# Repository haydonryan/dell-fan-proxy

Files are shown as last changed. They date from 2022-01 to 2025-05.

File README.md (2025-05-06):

# Dell Fan controller
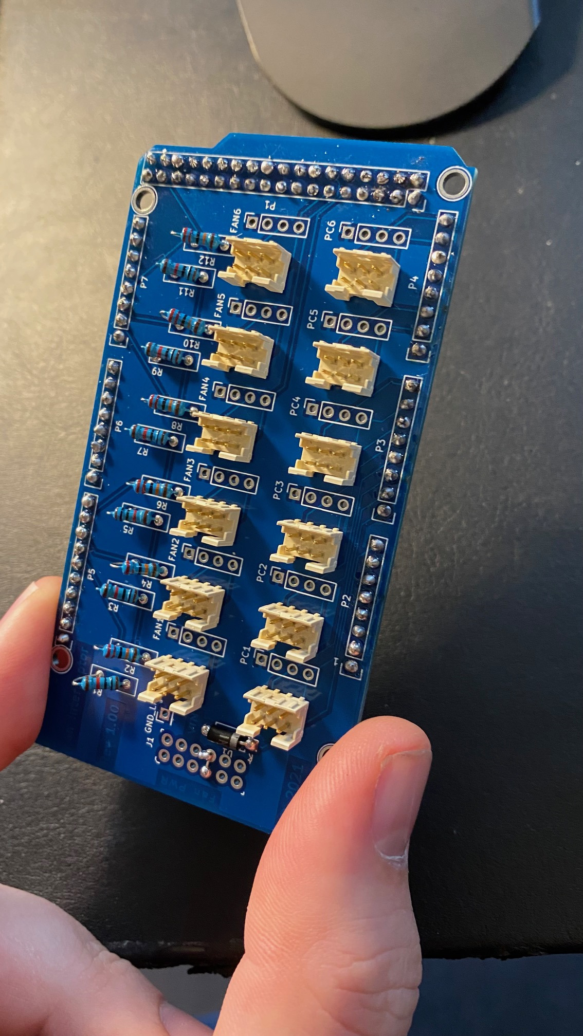
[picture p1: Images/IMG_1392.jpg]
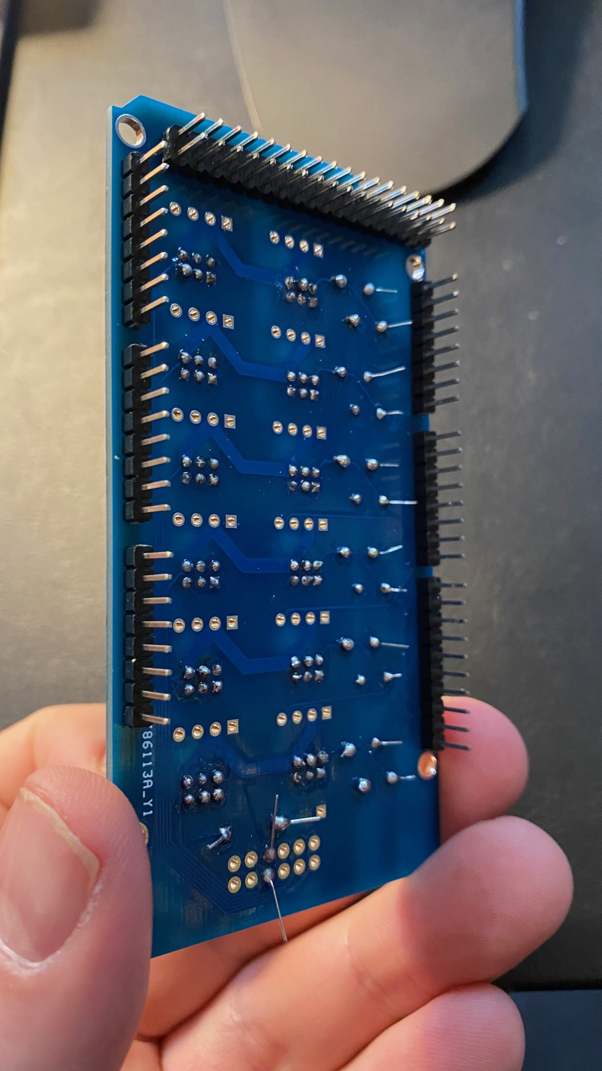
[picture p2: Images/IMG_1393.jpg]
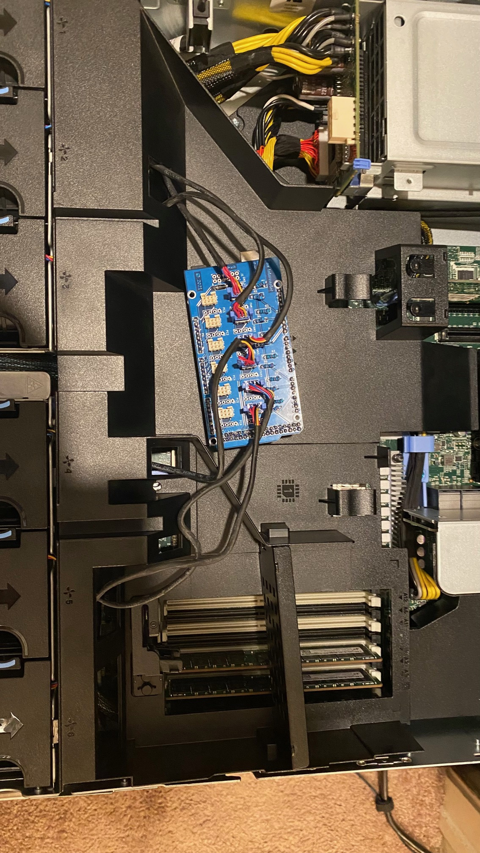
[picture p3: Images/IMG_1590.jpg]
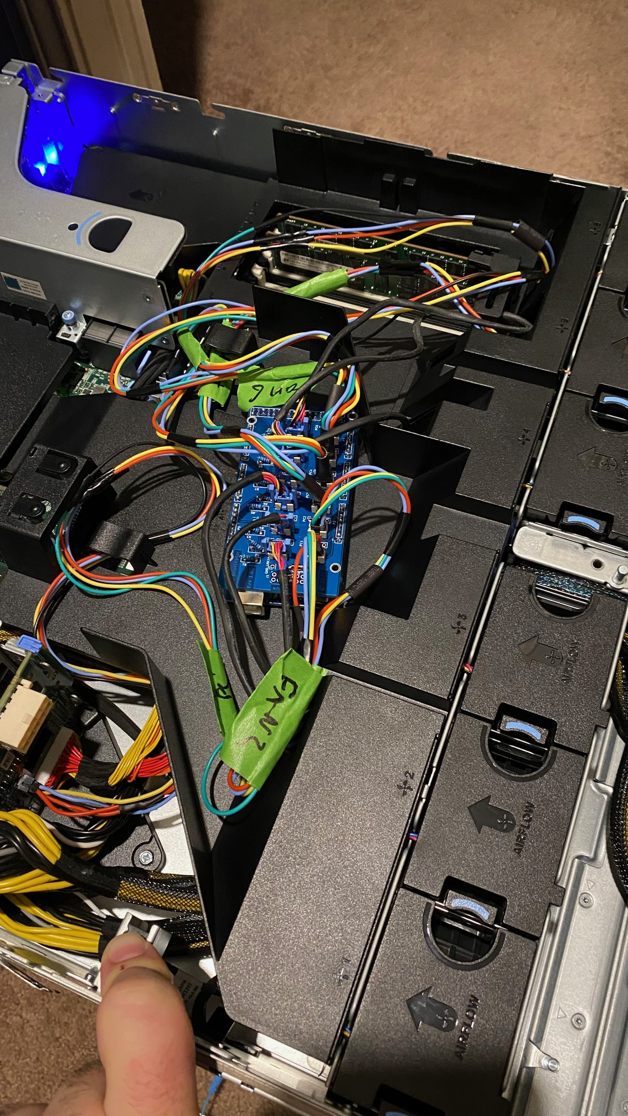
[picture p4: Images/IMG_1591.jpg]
         

Arduino Mega Fan Controller Sheild For R7515, R540 non hot swap fans.

# Background
I run an R7515 in my homelab. It's in a separate room upstairs (from my office) with the door open, I can hear it from my office downstairs.  It makes the room unusable that it sits in.

At 43% FAN, I can barely hear it from downstairs, 35% is really not too bad, up close.

The minimum fan speed and therefore noise is designed for a datacenter next to other heat generating servers with no noise contstraints, not a room in a house.
Plus I've got some non dell hardware( like many others do in homelabs) that the idrac controller doesn't know how to talk to, so the idrac just ramps the fans up to compensate for that one device.

I also noticed that at idle (which the machine sits 90% of the time) there is a 3 degree C differential between inlet and outlet temp, with the cpu being nice and cool.

# Why
- Dell support told me I'm not using the server for it's use case (Datacenter usage) - They're correct.
- Don't want to modify the firmware (it's signed anyways)
- Thought this would be an interesting project tom get more into electronics and control boards.

- As these machines come out of primary service in datacenters people are going to want to lab them - let's give them the power to do that!

# Disclaimer
- Will void your warranty
- Could cause your server to overheat
- Improper connection of fans can short out your motherboard!!!

- No responsibility taken for damaged hardware, loss of income, etc.

# Bill Of Materials:
- 6 Molex 2.00mm 2 Row, 6 Position Rectangular Receptical (Part # 0511100660) ~80c each https://www.digikey.com/en/products/detail/molex/0511100660/1144838?s=N4IgTCBcDaIOoFkCMAOArAdgwWgHIBEQBdAXyA
- 36 Molex Connector Socket 24-30AWG Crimp Gold (Part # 0503948054) 5c each https://www.digikey.com/en/products/detail/molex/0503948054/2404822?s=N4IgTCBcDaIAwFY4GYCcAWAHI9IC6AvkA

- 6 Amphenol ICC Conenctor Through Header Vert 6 Ppos 2.00mm (Part # 98414-G06-06LF) https://www.digikey.com/en/products/detail/amphenol-icc-fci/98414-G06-06LF/1535247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

- 1 Arduino Mega

- 24 AWG hookup wire - 5 colors preferred, but just be careful if you don't have different colors Cheaper on Amazon (https://www.amazon.com/CBAZYTM-Stranded-Flexible-Silicone-Electric/dp/B073RD76QD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)

- 6 TMP36 Temperature Sensors?? ~$1.50 https://www.digikey.com/en/products/detail/analog-devices-inc/TMP36GT9Z/820404

- Shrink wrap for wires
  - https://www.amazon.com/Eventronic-200pcs-Shrink-Tubing-Tubes/dp/B087JHB2CL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
  - https://www.amazon.com/High-Heat-Shrink-Tubing-Tube/dp/B0722HN8SW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
  - https://www.mouser.com/ProductDetail/Qualtek/Q2-F-RK4-1-16-11-6IN-39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

# Random bits of information

By measuring and pulling pins out of the fan, I was able to determine that the pins (with the plastic nib up, facing away from you in the order:
```
1   2   3
4   5   6
```

That the Wires are:

1. Blue - PWM
2. Not connected
3. Black - Ground
4. -| Red - 12v (this wire continues to fan)
5. -| Red - 12v Loopback
6. Yellow - Sense wire.

Arduino Pin	 Register
- 2	OCR3B
- 3	OCR3C
- 4	OCR4C
- 5	OCR3A
- 6	OCR4A
- 7	OCR4B
- 8	OCR4C
- 9	OCR2B
- 10	OCR2A
- 11	OCR1A
- 12	OCR1B
- 13	OCR0A
- 44	OCR5C
- 45	OCR5B
- 46	OCR5A

source: http://astro.neutral.org/arduino/arduino-pwm-pins-frequency.shtml

## Fri Dec 31 11:26:19 2021
Checked the continuity - on the new server board - there's a common 12v rail AND common 12v ground.  This means that I can easily check the fan project using the bench power supply.

So far so good on the server. Printed U shaped spacers to save the cables for fans 1-3.  Definitely prefer to do this over not having anything pushing the top up.

I did find that only fan 3 has 12v power when powered off, the rest must be switched somewhere in the motherboard.

Cable lengths:
- Fan 1 30cm
- Fan 2 26cm
- Fan 3 45cm
- Fan 4 40cm
- Fan 5 35cm
- Fan 6 40cm

Max length shrink tubing at the arduino end: 1-1.5cm

# July 2022 Update
I've been testing this during summer and noticed that as the inlet temperature approaches the limit "for this configuration" the fans ramp significantly.  This is clearly a preventative reaction rather than a reactive one.  Also ensuring that the hardware that is in the server is "compatilbe" aka listed on the compatabilty matrix certainly helps to reduce the speed of the fans.

# May 2024 Update
Have been running my server 24/7 for two years now with no ill effects.  No hardware failures, and just less noise.  It's not perfect and fans seem to surge slightly vs stay flat consistently.  It's not too big of an issue and could probably be adjusted by increasing the time the fans are averaged. Very happy with how this project is running.

# Making cable tips.
Put some shrink tubing on the 12v wire on the loop and the main wire before putting the terminal into the block. Stray 12v is SUPER bad.
Cut the terminal off the tape but leave the small bit of tape on for holding it steady.
put the terminal into the 1.3mm crimp size first all the way up to the tape - it should hold itself in there - making it easier to feed in the cable(s).

Make sure to crimp the actual insulation.
Don't have the wire come out too far as mounting this, the pins will potentially pus the pin out if there's not enough space.
https://www.youtube.com/watch?v=Ta55NTSBLN0

Do the dual power lead crimp first (it's the hardest)

# Possible improvements
It would be much safer to map the fan speed returned to idrac from the detected speed of the fan, not the requested rpm. That way if a fan fails, then idrac will throw a fault.

# Compatability
## Compatible Dell Servers
- R7515 (tested)
- R540 (untested)
- R7415 (untested)

## Incompatible Dell Servers
- R740 / R740XD
- R840
- R7615
- R550
- (anything where the fan plugs directly into the motherboard)

## Unsure
- R240 (unsure if can fit)
- R340 (unsure if can fit)
- R640 (unsure if can fit)

# Resources:
- Starting point: https://www.youtube.com/watch?v=UJK2JF8wOu8
- Replacement Fan: https://www.itcreations.com/product/119156
- Standard 4 pin fan pinout https://allpinouts.org/pinouts/connectors/motherboards/motherboard-cpu-4-pin-fan/
- https://pastebin.com/s49SWw1A
- https://github.com/Max-Sum/HP-fan-proxy/blob/master/hp_fan.ino
- https://www.avdweb.nl/arduino/misc/handy-functions
- https://www.reddit.com/r/homelab/comments/8wbogx/my_attempt_at_creating_a_circuit_board_that/
- https://www.reddit.com/r/homelab/comments/beuks5/silencing_the_hp_dl380_for_good/

- Setting the interrupt priority: https://www.youtube.com/watch?v=H3o08WE0zEI
- Delta Fan Datasheet for similar fan: https://www.mouser.com/datasheet/2/632/dele_s_a0011169984_1-2290125.pdf
- https://homeservershow.com/forums/topic/7294-faking-the-fan-signal/

- https://forum.arduino.cc/t/problem-measuring-4-pin-fan-rpm/666804/6
- http://www.benripley.com/diy/arduino/three-ways-to-read-a-pwm-signal-with-arduino/
- https://www.youtube.com/watch?v=nut1ZiiXzVU&t=143s

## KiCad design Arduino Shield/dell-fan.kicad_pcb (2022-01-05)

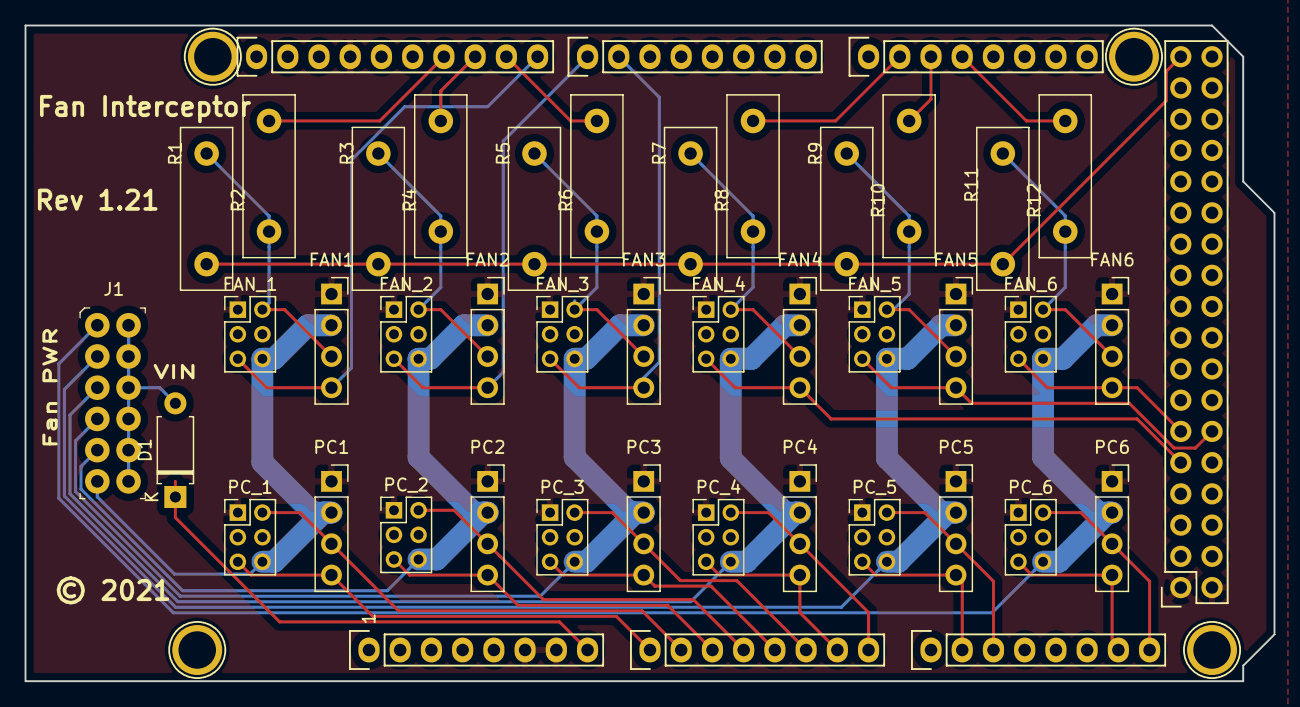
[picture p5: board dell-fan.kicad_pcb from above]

Board: 2 copper layers, 101.6 x 53.3 mm, 49 parts (0 on the bottom side), 40 nets.

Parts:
D1: 1N4007; D_A-405_P7.62mm_Horizontal
FAN1, FAN2, FAN3, FAN4, FAN5, FAN6: To Fan; PinSocket_1x04_P2.54mm_Vertical
FAN_1, FAN_2, FAN_3, FAN_4, FAN_5, FAN_6: To FAN; PinHeader_2x03_P2.00mm_Vertical
J1: Power; PinHeader_6x2_P2.54mm_Horizontal
P1: Digital; Socket_Strip_Arduino_2x18
P2: Power; Socket_Strip_Arduino_1x08
P3, P4: Analog; Socket_Strip_Arduino_1x08
P5: PWM; Socket_Strip_Arduino_1x10
P6: PWM; Socket_Strip_Arduino_1x08
P7: Communication; Socket_Strip_Arduino_1x08
P8, P10, P11, P13: CONN_01X01; Arduino_1pin
PC1, PC2, PC3, PC4, PC5, PC6: To PC; PinSocket_1x04_P2.54mm_Vertical
PC_1, PC_2, PC_3, PC_4, PC_5, PC_6: To PC; PinHeader_2x03_P2.00mm_Vertical
R1, R3, R5, R7, R9, R11: 10k; R_Box_L13.0mm_W4.0mm_P9.00mm
R2, R4, R6, R8, R10, R12: 220k; R_Box_L13.0mm_W4.0mm_P9.00mm

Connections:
+5V: P1.35, P1.36, R1.2, R3.2, R5.2, R7.2, R9.2, R11.2
/Vin: D1.1, P2.8
FAN1_12v: FAN1.2, FAN_1.6, J1.11, PC1.2, PC_1.6
FAN1_PWM: FAN1.4, FAN_1.5, P5.10
FAN1_TACH: P5.7, R2.2
FAN1_TACH_IN: FAN1.3, FAN_1.2, R1.1, R2.1
FAN2_12v: FAN2.2, FAN_2.6, J1.9, PC2.2, PC_2.6
FAN2_PWM: FAN2.4, FAN_2.5, P6.1
FAN2_TACH: P5.8, R4.2
FAN2_TACH_IN: FAN2.3, FAN_2.2, R3.1, R4.1
FAN3_12v: FAN3.2, FAN_3.6, J1.7, PC3.2, PC_3.6
FAN3_PWM: FAN3.4, FAN_3.5, P6.2
FAN3_TACH: P5.9, R6.2
FAN3_TACH_IN: FAN3.3, FAN_3.2, R5.1, R6.1
FAN4_12v: FAN4.2, FAN_4.6, J1.5, PC4.2, PC_4.6
FAN4_PWM: FAN4.4, FAN_4.5, P1.9
FAN4_TACH: P7.2, R8.2
FAN4_TACH_IN: FAN4.3, FAN_4.2, R7.1, R8.1
FAN5_12v: FAN5.2, FAN_5.6, J1.3, PC5.2, PC_5.6
FAN5_PWM: FAN5.4, FAN_5.5, P1.12
FAN5_TACH: P7.3, R10.2
FAN5_TACH_IN: FAN5.3, FAN_5.2, R9.1, R10.1
FAN6_12v: FAN6.2, FAN_6.6, J1.1, PC6.2, PC_6.6
FAN6_PWM: FAN6.4, FAN_6.5, P1.11
FAN6_TACH: P7.4, R12.2
FAN6_TACH_IN: FAN6.3, FAN_6.2, R11.1, R12.1
GND: FAN1.1, FAN2.1, FAN3.1, FAN4.1, FAN5.1, FAN6.1, FAN_1.1, FAN_2.1, FAN_3.1, FAN_4.1, FAN_5.1, FAN_6.1, P1.1, P1.2, P2.6, P2.7, P5.4, PC1.1, PC2.1, PC3.1, PC4.1, PC5.1, PC6.1, PC_1.1, PC_2.1, PC_3.1, PC_4.1, PC_5.1, PC_6.1
unnamed: D1.2, J1.2, J1.4, J1.6, J1.8, J1.10, J1.12
PC1_PWM: P3.1, PC1.4, PC_1.5
PC1_TACH: P3.2, PC1.3, PC_1.2
PC2_PWM: P3.3, PC2.4, PC_2.5
PC2_TACH: P3.4, PC2.3, PC_2.2
PC3_PWM: P3.5, PC3.4, PC_3.5
PC3_TACH: P3.6, PC3.3, PC_3.2
PC4_PWM: P3.7, PC4.4, PC_4.5
PC4_TACH: P3.8, PC4.3, PC_4.2
PC5_PWM: P4.2, PC5.4, PC_5.5
PC5_TACH: P4.3, PC5.3, PC_5.2
PC6_PWM: P4.7, PC6.4, PC_6.5
PC6_TACH: P4.8, PC6.3, PC_6.2

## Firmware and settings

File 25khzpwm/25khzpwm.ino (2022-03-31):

///////////////////////////////////////////////////////////////////////////
//
// Dell Fan Proxy
//
// For ATmega2560
//
///////////////////////////////////////////////////////////////////////////

const unsigned int NUMBER_OF_FANS = 6;

#define HISTORY_ARRAY_SIZE 5

// Pins to communiate with fan.
const int fan_pwm_pin_output[NUMBER_OF_FANS] = {8,7,6,46,45,44};     // Blue Wire.  Uses PWM registers and output   TODO: CHANGE PIN 11 to 44
const int fan_tach_pin_input[NUMBER_OF_FANS] = {11,10,9,15,16,17};      // Yellow Wire.

// Pins to communicate back to computer.
const int computer_pwm_input[NUMBER_OF_FANS] = {54,56,58,60,63,68};     // Blue Wire. uses pulseIn to read a sample pwm length
const int computer_tach_output[NUMBER_OF_FANS] = {55,57,59,61,64,69};   // Yellow Wire. Uses open drain to fake signal back.

///////////////////////////////////////////////////////////////////////////
// Fan speed map
// Modify the numbers in the fan_curve_map to change the points of the fan curve.
// The first value in each map determines where the fan speed is defined - eg if we read in that value it will output the second value.
// Strongly recommend - do not modify the first and last points unless you fully understand what you're doing.
///////////////////////////////////////////////////////////////////////////

const unsigned int FAN_MAP_POINTS = 11; // MIN 3 points

unsigned int fan_curve_map[FAN_MAP_POINTS][2] =
{ {0, 20},    // For input of zero - the second number is your absolute minimum speed, for example when the computer is off but idrac fan is still running.
  {10, 30},
  {20, 30},
  {30, 30},
  {40, 30},
  {50, 30},
  {60, 30},
  {70, 30},
  {80, 50},
  {90, 50},
  {100, 100} // leave as {100,100}
};

///////////////////////////////////////////////////////////////////////////

// Loop variables
unsigned long startTime;
unsigned int loopcounter = 0;

// Clamp variables
const unsigned int min_rpm = 30; // Fan still runs at 30, but 60 would be better for more airflow.
const unsigned int max_rpm = 320;

// Main datastructure for storing fan variables
struct fan_variable_structure {
  unsigned int idrac_pwm_percent_request[HISTORY_ARRAY_SIZE];       // Read: what fan speed is idrac requesting
  unsigned int idrac_rpm;                       // Var: desired rpm to generate for idrac

  unsigned long idrac_tach_increment;           // Var: the increment used for timing how often we need to pulse
  unsigned long idrac_start_time_micros;        // Var: last tick start time
  bool idrac_tach_open_drain_toggle;            // Var: state of open drain

  unsigned int fan_pwm_percent;                 // Write: output of the fan map that we send to the real fan
  unsigned int  fan_rpm;                        // Read: current RPM of the fan
};

fan_variable_structure fan[NUMBER_OF_FANS];

///////////////////////////////////////////////////////////////////////////
// Helper function to perform the fan curve mapping.
// Uses linear algebra to calcaulate points between control points
///////////////////////////////////////////////////////////////////////////
unsigned int map_fan_curve_pwm_based_on_input_pwm (unsigned int input_pwm ) {

  if (input_pwm > 100 ) input_pwm = 100;
  for (unsigned int i = 1; i < FAN_MAP_POINTS; i++) {
    if ( fan_curve_map[i - 1][0] <= input_pwm && input_pwm <= fan_curve_map[i][0] ) {
      float fan_curve_base = i - 1;
      float y, x;

      y = (fan_curve_map[i][1] - fan_curve_map[i - 1][1]);
      x = (fan_curve_map[i][0] - fan_curve_map[i - 1][0]);
      float ratio = y / x;

      return ( ( (input_pwm - fan_curve_map[i - 1][0] ) * ratio ) + fan_curve_map[i - 1][1] );

    }
  }


  return 100;    //default safe
}

unsigned int calculate_idrac_tach_pwm_based_on_actual_fan_pwm (unsigned int input_rpm ) {
  // Fake RPM
  // max we are likely to see is ~ 650HZ
  unsigned long rpm;
  rpm = input_rpm / 60L * 100 / 96;                              // 17k gives 16160 in bios 20k gives 19218 ~ 4-5% error
  return (1000000L / (4 * rpm))  ; // two pulses a second = 4 edges dumbass
}

///////////////////////////////////////////////////////////////////////////
//
//  SETUP
//
///////////////////////////////////////////////////////////////////////////

// https://www.robotshop.com/community/forum/t/arduino-101-timers-and-interrupts/13072
void setup() {
  // D44, D45 & D46 - Register 5
  TCCR5A = 0;  // reset Timer Counter Control Registers
  TCCR5B = 0;  // reset Timer Counter Control Register
  TCNT5 = 0;   // reset Timer Count Register

  // Set to PWM Phase Correct Mode WGM11+WGM13 See https://ww1.microchip.com/downloads/en/devicedoc/atmel-2549-8-bit-avr-microcontroller-atmega640-1280-1281-2560-2561_datasheet.pdf PG 145
  TCCR5A = _BV(COM5A1) | _BV(COM5B1) | _BV(COM5C1)| _BV(WGM11) ;   // _BV() is bit value equivalent to 1<<COM1A1
  TCCR5B = _BV(WGM13) | _BV(CS10);
  ICR5 = 320;  // Set the top of the count (Input Capture Register) in PWM Phase Correct mode
  OCR5A = 0;   // Reset Output Compare Registers
  OCR5B = 0;   // Reset Output Compare Registers
  OCR5C = 0;   // Reset Output Compare Registers

  // D6, D7, D8 - Register 4
  TCCR4A = 0;  // reset Timer Counter Control Registers
  TCCR4B = 0;  // reset Timer Counter Control Register
  TCNT4 = 0;   // reset Timer Count Register

  // Set to PWM Phase Correct Mode WGM11+WGM13 See https://ww1.microchip.com/downloads/en/devicedoc/atmel-2549-8-bit-avr-microcontroller-atmega640-1280-1281-2560-2561_datasheet.pdf PG 145
  TCCR4A = _BV(COM4A1) | _BV(COM4B1) | _BV(COM4C1)| _BV(WGM11) ;   // _BV() is bit value equivalent to 1<<COM1A1
  TCCR4B = _BV(WGM13) | _BV(CS10);
  ICR4 = 320;  // Set the top of the count (Input Capture Register) in PWM Phase Correct mode
  OCR4A = 0;   // Reset Output Compare Registers
  OCR4B = 0;   // Reset Output Compare Registers
  OCR4C = 0;   // Reset Output Compare Registers


  startTime = millis();
  for (int i=0; i< NUMBER_OF_FANS;i++) {
    fan[i].idrac_start_time_micros = micros();

    //Setup Pins to output PWM to
    pinMode(fan_pwm_pin_output[i], OUTPUT);

    // Setup Interrupts to read RPM from all tach pins
    pinMode(computer_pwm_input[i], INPUT);
    fan[i].fan_pwm_percent=60;
  }

  Serial.begin(115200);
  loopcounter = 0;

  // Disable i2C as pins 20 and 21 use it.
  pinMode(SDA, INPUT);
  pinMode(SCL, INPUT);

  Serial.println("Starting up...");

  OCR4C = fan[0].fan_pwm_percent*320 / 100;
  OCR4B = fan[1].fan_pwm_percent*320 / 100;
  OCR4A = fan[2].fan_pwm_percent*320 / 100;
  OCR5A = fan[3].fan_pwm_percent*320 / 100;
  OCR5B = fan[4].fan_pwm_percent*320 / 100;
  OCR5C = fan[5].fan_pwm_percent*320 / 100;

}

///////////////////////////////////////////////////////////////////////////
//
//  LOOP
//
///////////////////////////////////////////////////////////////////////////

void loop() {

  unsigned long duration;
  unsigned long current_time_in_micros = micros();

  //////////////////////////////////////////////////////
  // Toggle open drain based on the desired frequency
  //
  for (int i=0; i< NUMBER_OF_FANS;i++) {
    duration = (current_time_in_micros - fan[i].idrac_start_time_micros);
    if ( duration > fan[i].idrac_tach_increment) {  // toggle based on rpm
      fan[i].idrac_start_time_micros = current_time_in_micros;
      fan[i].idrac_tach_open_drain_toggle = !fan[i].idrac_tach_open_drain_toggle;
      openDrain(computer_tach_output[i], fan[i].idrac_tach_open_drain_toggle);
    }
  }

  //////////////////////////////////////////////////////
  // Once per second read the fan speed and print stats
  //
  if ((duration = millis() - startTime) > 1000) {  // update once per second

    for (int i=0; i< NUMBER_OF_FANS;i++) {
      // Measure Fan RPM
      fan[i].fan_rpm = read_fan_speed_in_rpm(fan_tach_pin_input[i]);

      // Read Requested PWM %
      insert(fan[i].idrac_pwm_percent_request, read_idrac_pwm_value_in_percentage (computer_pwm_input[i]));

      // Map idrac PWM % request to what we want fan PWM % to be
      unsigned long av = average(fan[i].idrac_pwm_percent_request);
      fan[i].fan_pwm_percent =  map_fan_curve_pwm_based_on_input_pwm(av);

      // Update RPM and tach that we want to generate for idrac
      fan[i].idrac_rpm = map_idrac_rpm_based_from_pwm(av);                  // pass through fan RPM.
      fan[i].idrac_tach_increment= calculate_idrac_tach_pwm_based_on_actual_fan_pwm(fan[i].idrac_rpm);    // calculate tach increment for desired fanspeed.
      fan[i].idrac_start_time_micros = micros();                                                          // reset tach timer
    }

    OCR4C = fan[0].fan_pwm_percent*320 / 100;
    OCR4B = fan[1].fan_pwm_percent*320 / 100;
    OCR4A = fan[2].fan_pwm_percent*320 / 100;
    OCR5A = fan[3].fan_pwm_percent*320 / 100;
    OCR5B = fan[4].fan_pwm_percent*320 / 100;
    OCR5C = fan[5].fan_pwm_percent*320 / 100;


    if (loopcounter % 2) {              // only display stats every 2 seconds
      print_fan_statistics();
    }

    startTime = millis();
  }

  ++loopcounter;
}

// pulses occur twice every rotation
unsigned int pulses_per_time_to_rpm( unsigned long total_pulses, unsigned int duration_in_miliseconds) {
  unsigned long fan_rpm = total_pulses  * 60 / 2 * 1000 / duration_in_miliseconds;

  return fan_rpm;
}


unsigned int read_idrac_pwm_value_in_percentage (unsigned int pin) {
   unsigned long high_duration, low_duration, percent;

    high_duration = pulseIn(pin, HIGH, 400);
    low_duration = pulseIn(pin, LOW, 400);

    if((low_duration + high_duration) == 0)  {
      int var = digitalRead(pin);
      if(var == LOW) {
        return 0;
        } else {
        return 100;
        }
      }
    percent = (100 * high_duration) / (low_duration + high_duration);
    if (percent > 100) percent=100;

    if(0) {  // debug flag
      Serial.println();
      Serial.print(" highduration = ");
      Serial.println(high_duration);

      Serial.print(" low duration = ");
      Serial.println(low_duration);

      Serial.print(" % = ");
      Serial.println(percent);
     }
    return percent;
}

unsigned int read_fan_speed_in_rpm(unsigned int pin) {
   unsigned long high_duration, low_duration, rpm;

    high_duration = pulseIn(pin, HIGH, 100000);
    low_duration = pulseIn(pin, LOW,   100000);
    rpm = 30000000 / (low_duration + high_duration); // two puses per second

    if(0) {  // debug flag
      Serial.println();
      Serial.print(" pin = ");
      Serial.println(pin);
      Serial.print(" highduration = ");
      Serial.println(high_duration);

      Serial.print(" low duration = ");
      Serial.println(low_duration);

      Serial.print(" rpm = ");
      Serial.println(rpm);

      Serial.print(" rpm = ");
      Serial.println(rpm);
     }
    return rpm;
}

void openDrain(byte pin, bool value)
{
  if (value)
    pinMode(pin, INPUT);
  else {
    pinMode(pin, OUTPUT);
    digitalWrite(pin, LOW);
  }
}

const unsigned int MAX_RPM_MAP_POINTS = 11;

unsigned int rpm_map[MAX_RPM_MAP_POINTS][2] =
{ {0, 0},    // leave as {0,0}
  {10, 2007},
  {20, 4045},
  {30, 6053},
  {40, 8091},
  {50, 10129},
  {60, 12077},
  {70, 14715},
  {80, 16213},
  {90, 16700},
  {100, 17000} // leave as {100,100}
};


unsigned int map_idrac_rpm_based_from_pwm(unsigned int input_pwm ) {

  if (input_pwm > 100 ) input_pwm = 100;

  for (unsigned int i = 1; i < MAX_RPM_MAP_POINTS; i++) {
    if ( rpm_map[i - 1][0] <= input_pwm && input_pwm <= rpm_map[i][0] ) {
      float fan_curve_base = i - 1;
      float y, x;

      y = (rpm_map[i][1] - rpm_map[i - 1][1]);
      x = (rpm_map[i][0] - rpm_map[i - 1][0]);
      float ratio = y / x;

      return ( ( (input_pwm - rpm_map[i - 1][0] ) * ratio ) + rpm_map[i - 1][1] );

    }
  }


  return rpm_map[MAX_RPM_MAP_POINTS - 1][1];    //default return RPMs for 100%
}

void print_fan_statistics() {
  char buffer[256];

  for (int i=0; i< NUMBER_OF_FANS; i++) {
    //sprintf(buffer, "Fan [%u] idrac: (%u%%, %u rpm) fan: (%u%%, %u rpm)", i,  fan[i].idrac_pwm_percent_request[0], fan[i].idrac_rpm, fan[i].fan_pwm_percent, fan[i].fan_rpm);
    sprintf(buffer, "Fan [%u] idrac: (%u%%, %u rpm) fan: (%u%%, %u rpm)", i,  fan[i].idrac_pwm_percent_request[0], fan[i].idrac_rpm, fan[i].fan_pwm_percent, fan[i].fan_rpm);
    Serial.println(buffer);
  }
  Serial.println();

  return;
}

unsigned long average(int *array) {
  unsigned long average=0;

  for (int i=0;i <HISTORY_ARRAY_SIZE;i++)  {
    average +=array[i];
  }
  average=average/HISTORY_ARRAY_SIZE;

  return average;
}

void insert(int *array, int value) {

  for (int i=HISTORY_ARRAY_SIZE-1;i >= 1;i--)  {
    array[i] = array[i-1];
  }
  array[0]= value;
}

// notes: default Falcon CPU speed 27% PWM

// Waveform Generation Mode bits (WGM): these control the overall mode of the timer. (These bits are split between TCCRnA and TCCRnB.)
// Clock Select bits (CS): these control the clock prescaler
// Compare Match Output A Mode bits (COMnA): these enable/disable/invert output A
// Compare Match Output B Mode bits (COMnB): these enable/disable/invert output B

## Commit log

2021-08-04 adding some comments, fixing some code formatting, and variable for clarity
    [25khzpwm.ino]
2021-08-13 Cleanup. PC interface. Helper func. 6 fan support
    I realize I haven't commited for a while, so need to fix that -
    committing now. Added a few helper functions
    [25khzpwm.ino]
2021-08-13 moving rpm, and interrupt count to data structure
2021-08-13 made passthrough to fan, improved output and cleanup
2021-08-13 map requested pwm through fan curve map
2021-08-13 correcting tach calculation to follow actual fan rpm
    [25khzpwm.ino]
2021-08-13 moving setting OCR1A to correct locations
    [25khzpwm.ino]
2021-08-13 adding mapping for tach output to idrac and removing test using internal pullup that failed
    [25khzpwm.ino]
2021-09-02 changing wire for arduino mega
2021-09-02 making fan interrupt count volatile
2021-09-02 correcting fan pwm
2021-09-11 expanding pin consts to support 6 fans
2021-09-11 adding additional interrupt callback functions
2021-09-11 adding comment to specify what board to use
2021-09-13 changing to timer 5 - for ports 44, 45, 46
2021-09-25 adding in PWM output to fan for all 6 fans
2021-09-25 setup interrupts to read from all channels
2021-09-26 adding case where idrac pwm request is zero - don't run fans.
2021-10-04 updating comment to include wire colors
2021-10-04 updating fan curve
2021-10-19 changing fans pins to suit board locations better
2021-10-19 reordering first 3 fans PWM to better suit board layout
2021-10-19 reordering second half of fan pwm pins to better suit board layout
2021-10-19 re-ordering fan tach pins to suit board layout
2021-10-19 initial commit of kicad arduino shield
    [dell-fan.kicad_pcb, dell-fan.sch]
2021-10-19 updating lcoation of PC pwm and tach signals for better board layout
2021-10-19 moved PC Tach and PWM to D554-d69
    [dell-fan.kicad_pcb, dell-fan.sch]
2021-10-19 fixed ground plane issue
    [dell-fan.kicad_pcb, dell-fan.sch]
2021-10-20 adding test code to count fan rpm not using interrupts
2021-10-20 fixing bug in insertion - this is why i should have had tests
    [25khzpwm.ino]
2021-10-23 Switching from interrupts to reading using pulseIn with smoothing
2021-10-23 setting sane minimum fan speed
2021-10-23 No interrupts means better pin placement
    [dell-fan.kicad_pcb, dell-fan.sch]
2021-11-08 commiting prototype run with gerber files
    [dell-fan-B_Cu.gbl, dell-fan-B_Mask.gbs, dell-fan-B_Paste.gbp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]
2021-12-25 updating readme after fan controller failed
2022-01-04 fixing two missing traces from production prototype
    [dell-fan.kicad_pcb]
2022-01-04 changing text to skilk screens
    [dell-fan.kicad_pcb]
2022-01-04 removing labels from pin blocks
    [dell-fan.kicad_pcb]
2022-01-05 making resistors larger
    [dell-fan.kicad_pcb]
2022-01-05 removing ground link as the board uses a common ground
    [dell-fan.sch]
2022-01-05 updating resistor size in schematic
    [dell-fan.sch]
2022-01-05 removing ground link from pcb design
    [dell-fan.kicad_pcb]
2022-01-05 fixing typo in fan speed source
    [25khzpwm.ino]
2022-03-31 adding more points to fan curve and increasing fan speed

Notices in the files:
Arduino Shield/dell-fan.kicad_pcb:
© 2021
